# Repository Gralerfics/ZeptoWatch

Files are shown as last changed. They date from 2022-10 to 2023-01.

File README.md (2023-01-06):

# ZeptoWatch

A smart watch based on STM32F405RGT6.

基于 STM32F405RGT6 的智能手表 / 大号手环，特点是可以执行用户编写的 Python 脚本（应用程序），并提供板上资源的 Python 库封装。
使能为 USB FS Device，设备可像 U 盘一样被识别，并且内有 FAT 文件系统，脚本直接拖入根目录即可。设备端可在应用列表以左滑手势刷新列表，固件会进行扫描。

**【Improving.】**

---

**/Documents**.

  - imgs: Shots. 一些展示图。
  - docs: Documents. 一些粗糙的 API 说明和脚本程序示例。

**/Firmware**: The firmware for ZeptoWatch.

  - UI based on LVGL. LVGL 实现的图形交互界面。
  - Drivers for peripherals on board. 驱动封装。
  - Type-C Support. Type-C 接口支持。
  - USB Mass Storage Class. 可识别为 USB 大容量存储设备。
  - FatFs on EEPROM. 在 EEPROM 上建立 FAT 文件系统。
  - Applying [PikaScript](https://github.com/pikasTech/pikascript) as a built-in interpreter. 采用 PikaScript 作为内置 Python 解释器。
  - ......

<div align="center">
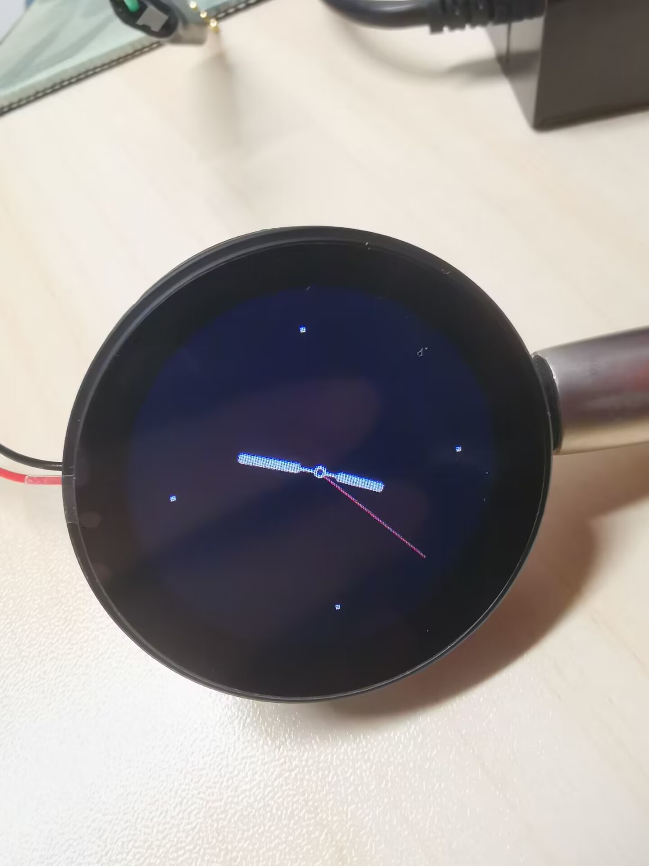
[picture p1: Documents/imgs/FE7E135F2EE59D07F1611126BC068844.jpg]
    
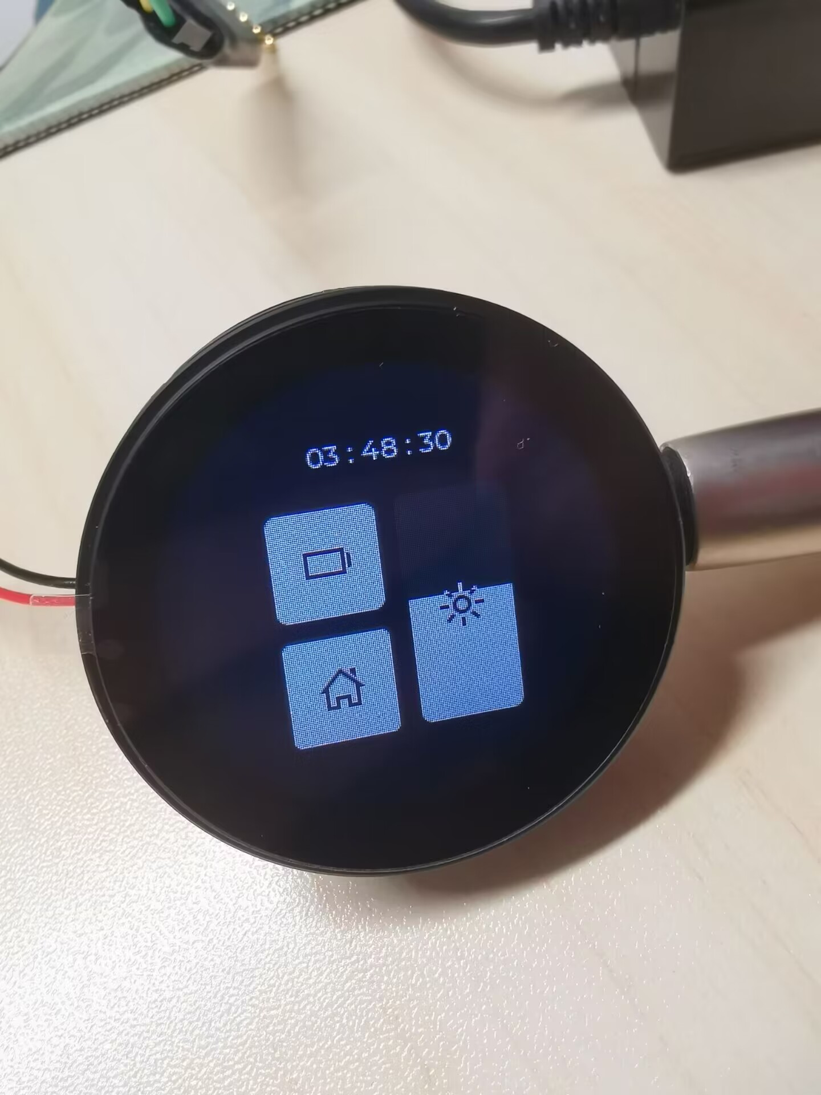
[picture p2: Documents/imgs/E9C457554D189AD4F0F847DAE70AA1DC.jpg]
    
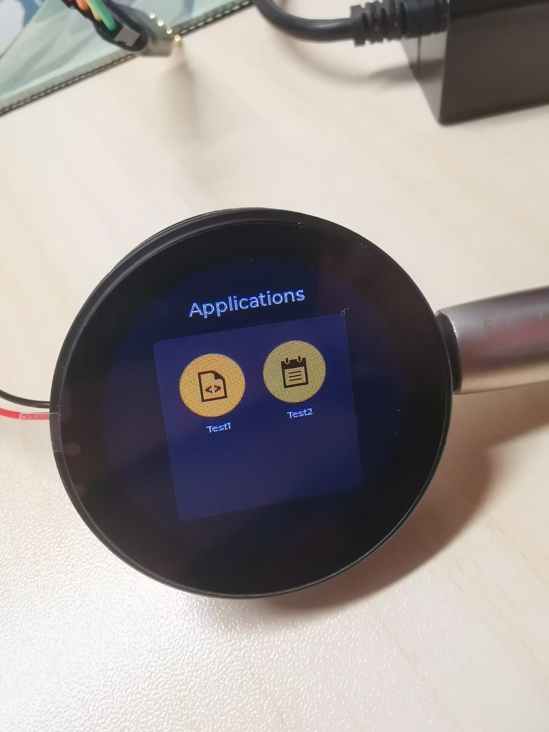
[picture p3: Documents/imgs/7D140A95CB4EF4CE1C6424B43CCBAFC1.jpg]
    
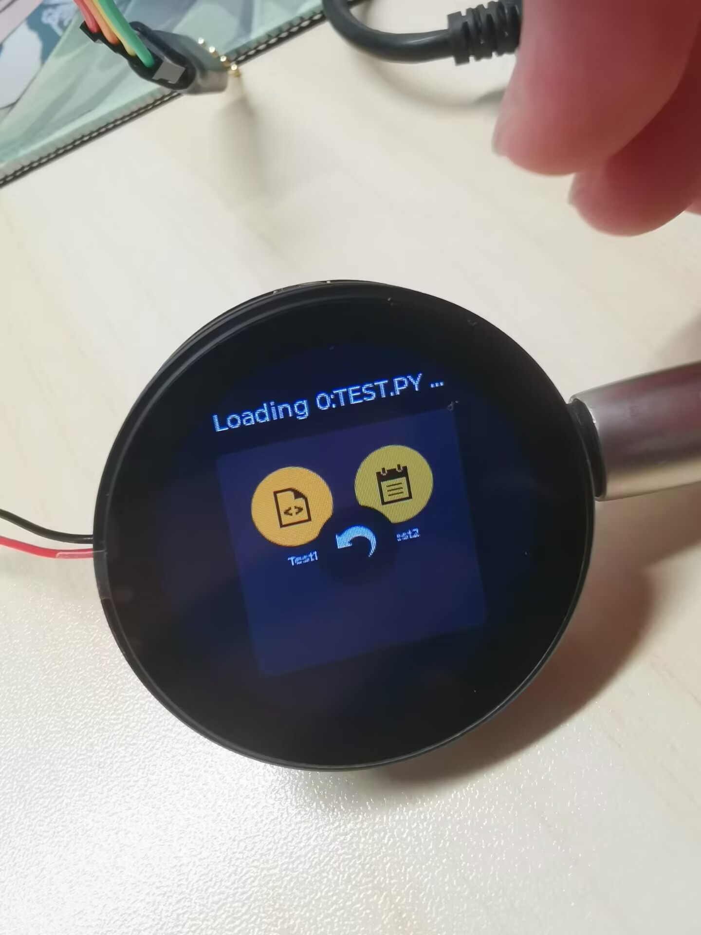
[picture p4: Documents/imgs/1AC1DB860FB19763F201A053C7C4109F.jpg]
    
</div>

**/Hardware**: PCBs & Schematics.

- Version 0.0: Test. 原型验证。

- Version 1.0: Polish up the schematics. Be not implemented. 初稿，存在问题。

- Version 2.0: There are some **mistakes** that would be modified in Ver.3.0. 第二版多处采取了一些更主流的方案，尚有一些小问题。

- Version 3.0: **Stacked design**. 第三版采用两块叠板设计。

<div align="center">
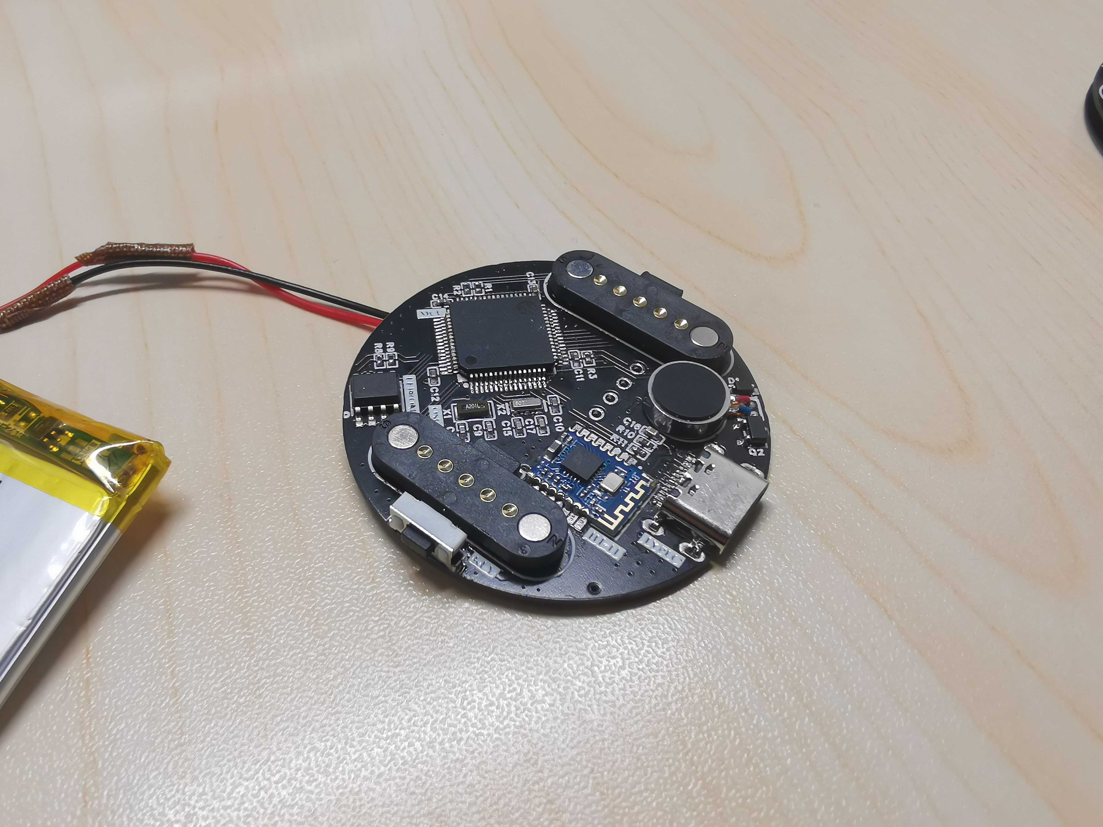
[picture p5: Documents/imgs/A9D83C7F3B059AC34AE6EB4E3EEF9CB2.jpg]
    
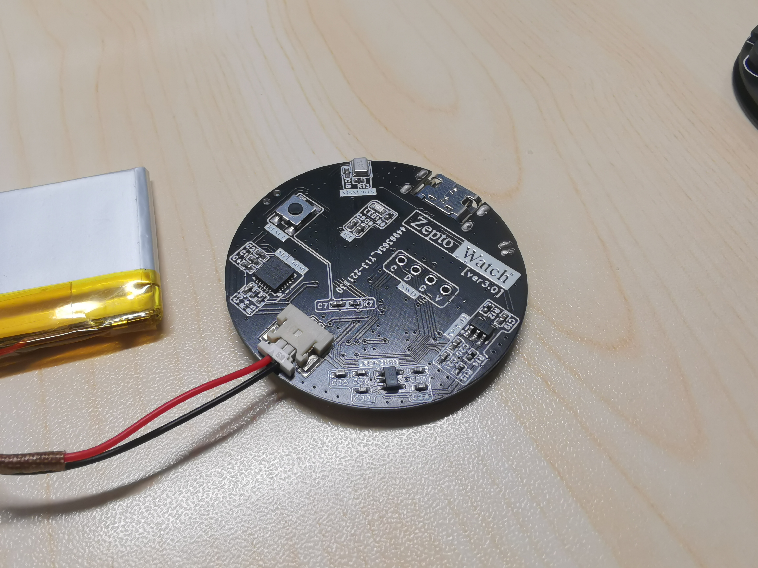
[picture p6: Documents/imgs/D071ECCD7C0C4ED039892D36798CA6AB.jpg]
    
</div>

<div align="center">
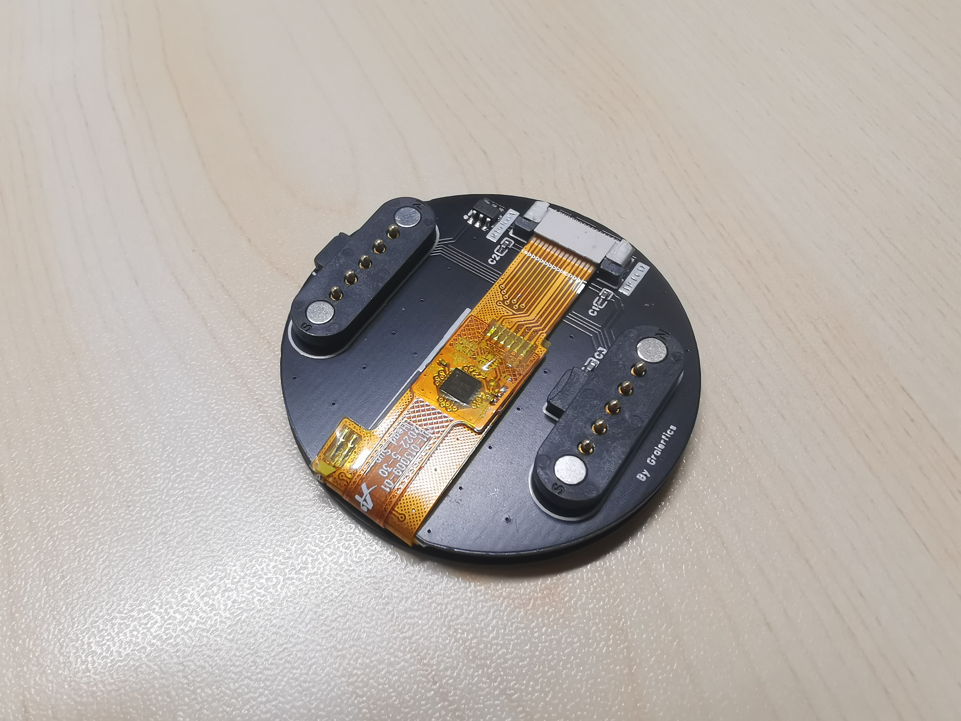
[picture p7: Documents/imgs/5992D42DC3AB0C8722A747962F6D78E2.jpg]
    
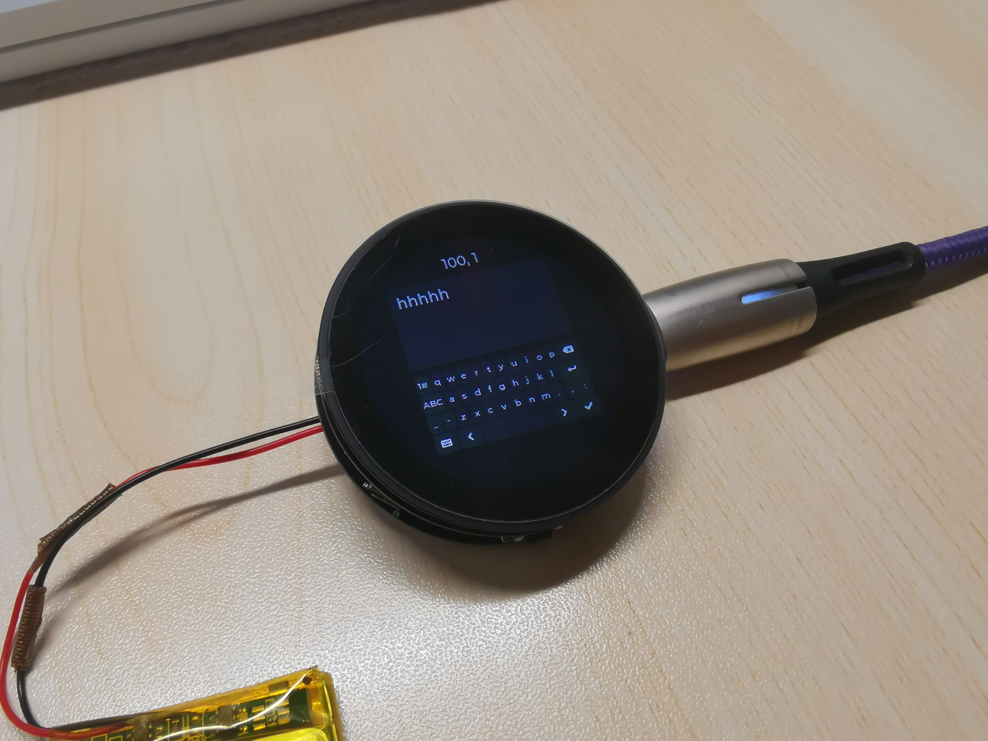
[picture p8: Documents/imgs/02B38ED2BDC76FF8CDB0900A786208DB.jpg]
    
</div>

- Version 4.0: Expectations. To be designed. 预期改进设计，详见第三版原理图注释。

**/Software/Scripts**: Some example scripts. 一些示例应用程序。

- BATUTIL.PY: 电源插拔检测和电池电压采样测试，字体大小变更测试。

- CALCAPP.PY: 简单的**计算器**，按钮阵列测试。

- FREQ.PY: 乱跳的**频谱显示**，麦克风、lvgl 样式、FFT (arm_math) 测试。

- LVTEST.PY: lvgl 测试，单个按钮与点击事件回调。

- MERITS.PY: **电 子 木 鱼**，内置图片资源获取、振动马达测试。

- SETTINGS.PY: 时间设置，roller 和 rtc 接口测试，设置界面已弃用改为内置。

- TEST.PY: 屏幕亮度变更、温度传感器测试。

- BALANCE.PY: 简单的**刚体模拟**小程序，用 IMU 加速度计给控件施加向下的模拟重力，顺便加了个边界反弹。

- GRAVITY.PY: BALANCE 的一个物体变为五个。

**/Structure**: Models in SolidWorks **(Just drafts, do not match the current PCB design)**. 无关的外壳设计，和实际设计的 PCB 不匹配，留档用。

---

An example script:
```python
###ICON=scripts;NAME=LightTest;COLOR=16751415###

import ZeptoWatchStdLib as zws
import ZeptoWatchPeriphLib as zwp

zwp.IMU.initialize()

i = 5
j = 1
while 1 == 1:
    zws.Display.setBrightness(i)
    if i >= 95:
        j = -1
    if i <= 5:
        j = 1
    i = i + j

    k = zwp.IMU.getTemperature()
    print(k)

    zws.System.delayMs(3)

###END###
```

The first line contains the basic information of the customized applications. Icons can be now only chosen from the built-in icons. By the way, the current implementation of the parsing method is just for testing and is very silly, so please follow the format strictly.
```python
###ICON=scripts;NAME=LightTest;COLOR=16751415###
```

The last line exists as another silly way to solve the problem of illegal characters at the end of the file when it is read by FatFs (I have temporarily no idea about where are they from. Maybe it has something to do with the fact that I edited the file by accessing the USB under Windows.).
```python
###END###
```

The output has been [retargeted](https://zhuanlan.zhihu.com/p/145801160) to USART6.
```python
print(k)
```

Drivers for resources on board are provided in the customized packages, including IMU, LCD, Microphone, etc.
```python
import ZeptoWatchStdLib as zws
import ZeptoWatchPeriphLib as zwp
```

If you want the rest of the system to be accessible at the same time, use ```ZeptoWatchStdLib.System.delayMs(time: int)``` in the script loop, which is implemented by FreeRTOS's ```osStatus osDelay (uint32_t millisec);```, in order to ensure that functions such as drop-down menus and clock ticking can remain active while the script is running.
```python
zws.System.delayMs(3)
```

A requirement from PikaScript is that all the spacing should be 4x spaces.
```python
while 1 == 1:
    zws.Display.setBrightness(i)
    if i >= 95:
        j = -1
    if i <= 5:
        j = 1
    i = i + j
```

---

Thanks for reading.

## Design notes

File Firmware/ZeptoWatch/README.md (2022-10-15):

# ZeptoWatch
Smart watch based on STM32F405RGT6.

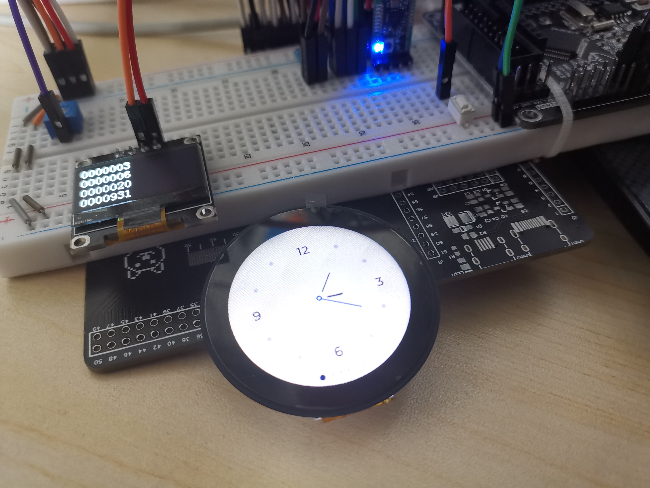
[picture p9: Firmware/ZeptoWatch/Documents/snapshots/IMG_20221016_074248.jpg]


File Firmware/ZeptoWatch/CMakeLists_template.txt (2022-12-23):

set(CMAKE_SYSTEM_NAME Generic)
set(CMAKE_SYSTEM_VERSION 1)
cmake_minimum_required(VERSION 3.23)

# specify cross-compilers and tools
set(CMAKE_C_COMPILER arm-none-eabi-gcc)
set(CMAKE_CXX_COMPILER arm-none-eabi-g++)
set(CMAKE_ASM_COMPILER  arm-none-eabi-gcc)
set(CMAKE_AR arm-none-eabi-ar)
set(CMAKE_OBJCOPY arm-none-eabi-objcopy)
set(CMAKE_OBJDUMP arm-none-eabi-objdump)
set(SIZE arm-none-eabi-size)
set(CMAKE_TRY_COMPILE_TARGET_TYPE STATIC_LIBRARY)

# project settings
project(ZeptoWatch C CXX ASM)
set(CMAKE_CXX_STANDARD 17)
set(CMAKE_C_STANDARD 11)

# PikaScript - [USER]
add_compile_definitions(PIKA_CONFIG_ENABLE)

#Uncomment for hardware floating point
add_compile_definitions(ARM_MATH_CM4;ARM_MATH_MATRIX_CHECK;ARM_MATH_ROUNDING)
add_compile_options(-mfloat-abi=hard -mfpu=fpv4-sp-d16)
add_link_options(-mfloat-abi=hard -mfpu=fpv4-sp-d16)

#Uncomment for software floating point
#add_compile_options(-mfloat-abi=soft)

add_compile_options(-mcpu=cortex-m4 -mthumb -mthumb-interwork)
add_compile_options(-ffunction-sections -fdata-sections -fno-common -fmessage-length=0)

# uncomment to mitigate c++17 absolute addresses warnings
#set(CMAKE_CXX_FLAGS "${CMAKE_CXX_FLAGS} -Wno-register")

# Enable assembler files preprocessing
add_compile_options($<$<COMPILE_LANGUAGE:ASM>:-x$<SEMICOLON>assembler-with-cpp>)

if ("${CMAKE_BUILD_TYPE}" STREQUAL "Release")
    message(STATUS "Maximum optimization for speed")
    add_compile_options(-Ofast)
elseif ("${CMAKE_BUILD_TYPE}" STREQUAL "RelWithDebInfo")
    message(STATUS "Maximum optimization for speed, debug info included")
    add_compile_options(-Ofast -g)
elseif ("${CMAKE_BUILD_TYPE}" STREQUAL "MinSizeRel")
    message(STATUS "Maximum optimization for size")
    add_compile_options(-Os)
else ()
    message(STATUS "Minimal optimization, debug info included")
    #    add_compile_options(-Og -g)
    add_compile_options(-O0)
endif ()

include_directories(
        /
        Core/Inc
        Drivers/STM32F4xx_HAL_Driver/Inc
        Drivers/STM32F4xx_HAL_Driver/Inc/Legacy
        Drivers/CMSIS/Device/ST/STM32F4xx/Include
        Drivers/CMSIS/Include
        FATFS/App
        FATFS/Target
        Libraries
        Libraries/lvgl
        Libraries/lvgl/porting
        Libraries/lvgl/src/core
        Libraries/PikaScript/pikascript-api
        Libraries/PikaScript/pikascript-core
        Middlewares/ST/ARM/DSP/Inc
        Middlewares/ST/STM32_USB_Device_Library/Class/MSC/Inc
        Middlewares/ST/STM32_USB_Device_Library/Core/Inc
        Middlewares/Third_Party/FatFs/src/
        Middlewares/Third_Party/FreeRTOS/Source/CMSIS_RTOS
        Middlewares/Third_Party/FreeRTOS/Source/include
        Middlewares/Third_Party/FreeRTOS/Source/portable/GCC/ARM_CM4F
        USB_DEVICE/App
        USB_DEVICE/Target
        ZeptoWatch
        ZeptoWatch/BuiltIns
        ZeptoWatch/BuiltIns/UI
        ZeptoWatch/Drivers/battery
        ZeptoWatch/Drivers/bt
        ZeptoWatch/Drivers/eeprom
        ZeptoWatch/Drivers/imu
        ZeptoWatch/Drivers/lcd
        ZeptoWatch/Drivers/microphone
        ZeptoWatch/Drivers/rtc
        ZeptoWatch/Drivers/system
        ZeptoWatch/Drivers/vibrator
        ZeptoWatch/Ports
        ZeptoWatch/Tasks
        ZeptoWatch/UI
        ZeptoWatch/Utils
)

add_definitions(-DUSE_HAL_DRIVER -DSTM32F405xx)

file(GLOB_RECURSE SOURCES
        "Core/*.*"
        "Drivers/*.*"
        "FATFS/*.*"
        "Libraries/lvgl/*.*"
        "Libraries/PikaScript/*.c"
        "Libraries/PikaScript/*.h"
        "Middlewares/*.*"
        "startup/*.*"
        "USB_DEVICE/*.*"
        "ZeptoWatch/*.*"
)

set(LINKER_SCRIPT ${CMAKE_SOURCE_DIR}/STM32F405RGTx_FLASH.ld)

add_link_options(-Wl,-gc-sections,--print-memory-usage,-Map=${PROJECT_BINARY_DIR}/${PROJECT_NAME}.map)
add_link_options(-mcpu=cortex-m4 -mthumb -mthumb-interwork)
add_link_options(-T ${LINKER_SCRIPT})

add_executable(${PROJECT_NAME}.elf ${SOURCES} ${LINKER_SCRIPT})

# Arm-math - [USER]
add_library(arm_math STATIC IMPORTED)
set_target_properties(arm_math PROPERTIES IMPORTED_LOCATION ${CMAKE_SOURCE_DIR}/Middlewares/ST/ARM/DSP/Lib/libarm_cortexM4lf_math.a)
target_link_libraries(${PROJECT_NAME}.elf arm_math)

set(HEX_FILE ${PROJECT_BINARY_DIR}/${PROJECT_NAME}.hex)
set(BIN_FILE ${PROJECT_BINARY_DIR}/${PROJECT_NAME}.bin)

add_custom_command(TARGET ${PROJECT_NAME}.elf POST_BUILD
        COMMAND ${CMAKE_OBJCOPY} -Oihex $<TARGET_FILE:${PROJECT_NAME}.elf> ${HEX_FILE}
        COMMAND ${CMAKE_OBJCOPY} -Obinary $<TARGET_FILE:${PROJECT_NAME}.elf> ${BIN_FILE}
        COMMENT "Building ${HEX_FILE}
Building ${BIN_FILE}")

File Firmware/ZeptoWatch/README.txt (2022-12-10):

1、为了可以格式化小容量空间，FATFS的原文件需要修改，而CubeMX重新生成会覆盖，故需手动修改ff.c。
修改参考：https://blog.csdn.net/qq_40824852/article/details/123357022，第六部分：大致就是某处“sz_vol -= b_vol;”注释掉；某处“if (sz_vol < 128) return FR_MKFS_ABORTED;”注释掉。
当然，也只有未格式化时需要f_mkfs，如果已经格式化了之后不损坏就不需要管了，这里作个记录。

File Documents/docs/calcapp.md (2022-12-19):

# Comments for Calculator Example

---

```python
###ICON=calc;NAME=Calculator;COLOR=13726207;###

import pika_lvgl as lv
import ZeptoWatchStdLib as zws

instr = ''
sym = ''
a = 0
b = 0

lb = lv.label(zws.Display.getField())
lb.set_align(lv.ALIGN.CENTER)
lb.set_width(140)
lb.set_y(-80)
lb.set_text(instr)

btnCode = ['7', '8', '9', '+', '4', '5', '6', '-', '1', '2', '3', '*', '.', '0', '=', '/']
btnList = []
lbList = []

def event_cb_btns(e):
    code = e.get_code()
    if code == lv.EVENT.CLICKED:
        global instr, sym, a, b
        idx = int(e.get_target().get_id())
        if btnCode[idx] == '=':
            if instr == '':
                b = 0
            else:
                b = float(instr)
            res = ''
            if sym == '+':
                res = str(a + b)
            elif sym == '-':
                res = str(a - b)
            elif sym == '*':
                res = str(a * b)
            elif sym == '/':
                if b == 0:
                    res = 'Math Error!'
                else:
                    res = str(a / b)
            else:
                res = str(b)
            lb.set_text(res)
            a = float(res)
            sym = '='
            instr = ''
        elif btnCode[idx] == '+' or btnCode[idx] == '-' or btnCode[idx] == '*' or btnCode[idx] == '/':
            if sym == '':
                if instr == '':
                    a = 0
                else:
                    a = float(instr)
            sym = btnCode[idx]
            instr = ''
            lb.set_text(sym)
        else:
            if sym == '=':
                sym = ''
            instr += btnCode[idx]
            lb.set_text(instr)

for i in range(16):
    btnList.append(lv.btn(zws.Display.getField()))
    btnList[i].set_id(str(i))
    btnList[i].set_align(lv.ALIGN.CENTER)
    btnList[i].set_size(32, 32)
    btnList[i].set_x((i % 4) * 40 - 60)
    btnList[i].set_y(int(i / 4) * 40 - 45)
    btnList[i].add_event_cb(event_cb_btns, lv.EVENT.CLICKED, 0)

    lbList.append(lv.label(zws.Display.getField()))
    lbList[i].set_align(lv.ALIGN.CENTER)
    lbList[i].set_x((i % 4) * 40 - 60)
    lbList[i].set_y(int(i / 4) * 40 - 45)
    lbList[i].set_text(btnCode[i])

while 1 == 1:
    zws.System.delayMs(5)

###END###
```

1. 首先程序开头和结尾的的注释：

```python
###ICON=calc;NAME=Calculator;COLOR=13726207;###
...
###END###
```

- 首先开头的注释包含应用信息。

  - **参数**：
  `ICON`指定图标，目前可选`scripts (默认)`、`timer`、`calc`、`canlendar`、`settings`、`info`、`clock`、`check`、`notes`；
  `NAME`指定应用名称，默认为文件路径；
  `COLOR`指定应用图标颜色，十进制，转换为十六进制后有六位，每两位分别代表`RGB (0 - 255)`值。 
  例如：上例中`13726207`为十六进制`0xD171FF`，`D1`为`209`代表红色值，依此类推。用 Windows 自带计算器的程序员模式看就行。

  - **要求**：
开头三个井号是必须的，结束至少一个井号，写三个对称好看点；
内部每个参数用分号隔开，顺序可以变动，最后一个参数结束也要加分号；
参数名和参数值用一个等号连接；
参数名要大写；参数值长度不超过`30`；
非法参数名会被忽略，但长度不要超过`8`；
未成功赋值的参数将使用默认值`ICON=scripts;NAME=[文件名];COLOR=16751415`。
当然，因为解析部分的逻辑很简单粗暴，按照示例的格式来是最稳的。

- 结尾的注释最好加上，先前读取程序时末尾有非法字符，暂时的解决方案就是检测`#END#`然后把后面的内容都忽略掉。

2. 接下来是导入所需的包：
```python
import pika_lvgl as lv
import ZeptoWatchStdLib as zws
```

这里用到了 UI 组件所以导入`pika_lvgl`包，便于使用起别名为`lv`；同样地，因为用到了`delayMs()`和`getField()`等，也要导入`ZeptoWatchStdLib`包，起别名为`zws`。

虽然其实初始化时几个包都导入了，不过为了完整性还是规范些写。

3. 下面先说主循环：
```python
while 1 == 1:
    zws.System.delayMs(5)
```

主循环中如果不想阻塞系统其它任务请调用`zws.System.delayMs()`。该函数背后是`FreeRTOS`的`osDelay`，在延时中会由`RTOS`调度执行系统其他任务，比如绘制 UI、亮度和电量同步等。

缺点就是最小时间单位长达一毫秒——但如果不调用就会阻塞，UI 不会更新，系统也会卡死，因为触摸检测之类都被阻塞了，进了死循环。当然，`ZeptoWatchStdLib`也提供了一个`.Display.lvglUpdate()`方法，用于手动触发`lvgl`任务处理，可以使 UI 更新和触摸继续工作，但亮度和电量检测之类还是罢工，晚些都把手动的接口添加上，再加个配套的微秒级阻塞延时。

4. 然后以创建一个 Label 为例看下 UI 组件的配置：
```python
lb = lv.label(zws.Display.getField())
lb.set_align(lv.ALIGN.CENTER)
lb.set_width(140)
lb.set_y(-80)
```

这里是用构造方法`lv.label()`创建了一个`label`对象，参数是其父对象。UI 界面是一个树形结构，组件可以一级套一级，所以要传入它的父对象。

这里使用`zws.Display.getField()`获取应用界面的根对象(源代码中看就是`ui_Appfield`)。`lvgl`还提供了一个`lv.scr_act()`方法用于获取当前活动中的屏幕，不使用而专门封装一个`getField()`是为了防止例如应用界面加载时拉下下拉菜单导致组件画到下拉菜单上这种情况出现，所以尽量使用`getField()`。

然后创建后把对象保存到`lb`变量，之后对其进行操作即可。下面使用的都是`lv_obj`的成员方法，具体可以见`api.md`和`pika_lvgl.pyi`。

`lb.set_align`设置对齐方式，设为`lv.ALIGN.CENTER`的直观表现就是坐标系的原点`(0, 0)`之后就被定位在了屏幕正中。

设置居中对齐后，`lb.set_y(-80)`就把标签移动到比中心高`80px`的地方。横坐标默认为`0`。注：屏幕大小为`240x240px`。

`lb.set_width`设置宽度为`140px`，不设置也行，标签对象的默认宽度是适应内容宽度。

设置完后可以用`label`的成员方法设置标签的内容，例如`lb.set_text(str)`，`str`为字符串。

5. 可以看到`PikaScript`目前也支持`list`数据结构：
```python
btnCode = ['7', '8', '9', '+', '4', '5', '6', '-', '1', '2', '3', '*', '.', '0', '=', '/']
btnList = []
lbList = []
...
for i in range(16):
    btnList.append(lv.btn(zws.Display.getField()))
    btnList[i].set_id(str(i))
    btnList[i].set_align(lv.ALIGN.CENTER)
    btnList[i].set_size(32, 32)
    btnList[i].set_x((i % 4) * 40 - 60)
    btnList[i].set_y(int(i / 4) * 40 - 45)
    btnList[i].add_event_cb(event_cb_btns, lv.EVENT.CLICKED, 0)

    lbList.append(lv.label(zws.Display.getField()))
    lbList[i].set_align(lv.ALIGN.CENTER)
    lbList[i].set_x((i % 4) * 40 - 60)
    lbList[i].set_y(int(i / 4) * 40 - 45)
    lbList[i].set_text(btnCode[i])
```

前面的标签是计算器的输入和输出显示标签，被放在屏幕上端。这里则是`16`个按键阵列的生成。

首先定义好几个`list`，一个存放各个按键的标签字符串，一个存放十六个`btn`，一个存放十六个`label`对象。

下面`for`循环（可以看到`range`也支持），按钮和标签分别创建后添加至列表，然后进行设置，具体的和前面一样就不说了，看函数名字就能猜。

特别的是`btn`还用了一个`.add_event_cb`方法，用于绑定事件，见下。

6. 关于事件绑定：
```python
def event_cb_btns(e):
    code = e.get_code()
    if code == lv.EVENT.CLICKED:
        idx = int(e.get_target().get_id())
        ...

for i in range(16):
    btnList[i].set_id(str(i))
    ...
    btnList[i].add_event_cb(event_cb_btns, lv.EVENT.CLICKED, 0)

```

按钮点击之后需要处理，这时候就需要给按钮绑定点击事件。`add_event_cb`三个参数，第一个是回调函数的名字，第二个是事件类型，第三个是`user_data`。

回调函数前边定义了放进来就行。

事件类型参见文档`EVENT`，常用的就点击，也就是`lv.EVENT.CLICKED`。

`user_data`可以给回调函数传递数据，比如像上面十六个按钮共用一个回调函数，可以用这个参数来区分到底是哪个按钮被点击了。但是获取这个数据的接口他好像没封装，所以这种方法先不能用，就传个`0`进去空着。
替代的方法也就是上面用到的，给每个`btn`对象`set_id`设置一个`id`，在回调函数中查看点击对象的`id`来区分。

回调函数接受一个参数，假设叫`e`。这个`e`目前由两个方法，一个是`.get_code()`，可以获取触发的事件类型，每次要先判断一下是不是你要的事件，具体见上；另一个是`.get_target()`，返回触发事件的对象，比如你按了第七个按钮，就可以获取第七个按钮的对象引用，所以可以通过这个方法来获取按钮的`id`，区分是哪个按钮被点击了，具体见上。

上面实例中回调函数大半部分是混乱但能跑的计算器逻辑，涉及到按钮点击的部分就是上面截取出的部分。

7. 一些备注：

这是关于`Python`语法的，函数中获取全局变量记得`global`。

`Python`的`for`、`if`结构和其他的不太一样，注意一下。还有逻辑运算不是`&&`之类，而是`and`之类。

所有缩进都是四个空格为基础，而不是等缩进就行，这是`PikaScript`的要求。

---

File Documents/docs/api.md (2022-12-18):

# APIs for ZeptoWatch Scripts

---

0. `PikaScript` (Subset of Python3)

- 

1. `PikaStdLib` (Package, Recommend: `import PikaStdLib as std`)

- 

2. `ZeptoWatchStdLib` (Package, Recommend: `import ZeptoWatchStdLib as zws`)

```python
class System:
    def delayMs(self, time: int): ...
    # 用 FreeRTOS 的 osDelay 实现, 调用它以允许其它任务并行

class Display:
    def getField(self) -> lv_obj: ...
    # 获取应用界面屏幕的对象, 创建 lvgl 对象时作为根对象, 退出应用时会被清空.
    # 不建议使用 pika_lvgl.scr_act(), 如果在应用界面进入下拉栏时调用会导致组件显示到下拉栏.
    # 总之就是创建最初一级 UI 对象时用到, 例如: lb = lv.label(zws.Display.getField()).
    # 上例中利用 lv.label() 创建 label 对象, 使用 getField 获取应用页面作为其父对象.
    
    def setBrightness(self, val: int): ... 
    # 设置屏幕亮度, 值为 [0, 100].
    # 已经经过映射, 也就是 0 不代表彻底熄灭, 且亮暗变化更连续些.
    
    def getBrightness(self) -> int: ...
    # 获取当前屏幕亮度, 按键熄屏导致的亮度变化不算.

class Clock:
    def getHours(self) -> int: ...
    def getMinutes(self) -> int: ...
    def getSeconds(self) -> int: ...
    def getYear(self) -> int: ...
    def getMonth(self) -> int: ...
    def getDay(self) -> int: ...
    def getWeekDay(self) -> int: ...
    # 以上分别为获取实时时钟的时、分、秒、年、月、日、星期.
```

3. `ZeptoWatchPeriphLib` (Package, Recommend: `import ZeptoWatchPeriphLib as zwp`)

```python
class IMU:
    def initialize(self): ...
    # 初始化 IMU, 使用 IMU 前调用. 不过系统开机时自动初始化了, 可以不管.
    
    def getTemperature(self) -> int: ...
    # 获取温度原始值, 好像为温度值乘 100 后的结果.
    
    def getGyroscope(self) -> list: ...
    # 获取三轴角加速度, 返回一个三元素列表.
    # [-32768, 32767] 对应 [-2000dps, 2000dps], dps: degree per second.
    
    def getAccelerometer(self) -> list: ...
    # 获取三轴加速度, 返回一个三元素列表.
    # [-32768, 32767] 对应 [-2g, 2g].

class Battery:
    def isCharging(self) -> int: ...
    # 获取 Type-C 口是否接上电源.
    
    def getRawData(self) -> int: ...
    # 获取电池 ADC 采样原始值, 不准得很, 忽略吧.

class Microphone:
    def startSampling(self): ...
    # 开启麦克风采样, 使用前要调用.
    
    def stopSampling(self): ...
    # 停止麦克风采样.

    def getRawData(self) -> int: ...
    # 获取麦克风当前采样值.

class Vibrator:
    def vibrate(self, ms: int, pulse: int): ...
    # 振动马达振动, 持续 ms 毫秒, 占空比 pulse. 虽然效果不太舒适的样子.
    # 这玩意快能当蜂鸣器了 ...

    def stop(self): ...
    # 强制停止振动.
```

4. `pika_lvgl` (Package, Recommend: `import pika_lvgl as lv`)

东西很多, 可以去下个 Squareline Studio 鼠标点点看, 都是和 API 对应的. 当然, 简单能用的界面就用 label 和 btn 也足够了.

- `lv_obj`, 所有 lvgl 对象的父类, 挑一些注释一下.

```python
class lv_obj:
    def __init__(self, parent: lv_obj): ...
    
    def add_state(self, state: int): ...
    # 添加 state, 可取值见后 STATE.
    
    def add_flag(self, flag: int): ...
    def clear_flag(self, flag: int): ...
    # 添加或清除 flag, 例如隐藏等, 具体见后 flag_t
    
    def add_event_cb(self, event_cb: any, filter: int, user_data: pointer): ...
    # 添加回调函数. 例如: btn.add_event_cb(event_cb_btn, lv.EVENT.CLICKED, 0).
    # 上例为按钮添加了点击事件, btn 若被点击就会执行 event_cb_btn(e) 函数, 并传入一个 lv_event 参数.
    # lv_event 和 EVENT 可取值见后.
    
    def add_style(self, style: style_t, selector: int): ...
    # 添加样式, 见后 style_t.
    
    def set_pos(self, x: int, y: int): ...
    def set_x(self, x: int): ...
    def set_y(self, y: int): ...
    def set_size(self, w: int, h: int): ...
    def refr_size(self) -> int: ...
    def set_width(self, w: int): ...
    def set_height(self, h: int): ...
    def set_content_width(self, w: int): ...
    def set_content_height(self, h: int): ...
    # 各种设置大小、位置的 API.
    
    def set_layout(self, layout: int): ...
    def is_layout_positioned(self) -> int: ...
    def mark_layout_as_dirty(self): ...
    def update_layout(self): ...
    # 关于 Layout 的.
    
    def set_align(self, align: int): ...
    def align(self, align: int, x_ofs: int, y_ofs: int): ...
    def align_to(self, base: lv_obj, align: int, x_ofs: int, y_ofs: int): ...
    def center(self): ...
    # 关于对齐的, ALIGN 也见后. 前面设置坐标的基准是 ALIGN.
    # 例如: 如果设置为 lv.ALIGN.CENTER, 则正中间为坐标原点 (0,0).
    
    def get_x(self) -> int: ...
    def get_x2(self) -> int: ...
    def get_y(self) -> int: ...
    def get_y2(self) -> int: ...
    def get_x_aligned(self) -> int: ...
    def get_y_aligned(self) -> int: ...
    def get_width(self) -> int: ...
    def get_height(self) -> int: ...
    def get_content_width(self) -> int: ...
    def get_content_height(self) -> int: ...
    def get_self_width(self) -> int: ...
    def get_self_height(self) -> int: ...
    # 尺寸和位置参数的获取
    
    def refresh_self_size(self) -> int: ...
    def refr_pos(self): ...
    def move_to(self, x: int, y: int): ...
    def move_children_by(self, x_diff: int, y_diff: int, ignore_floating: int): ..
    def transform_point(self, p: point_t, recursive: int, inv: int): ...
    def invalidate(self): ...
    # 没用过不知道
    
    def is_visible(self) -> int: ...
    # 是否可见
    
    def set_ext_click_area(self, size: int): ...
    def hit_test(self, point: point_t) -> int: ...
    # 关于点击
    
    def set_flex_flow(self, flow: int): ...
    def set_flex_grow(self, value: int): ...
    def set_flex_align(self, main_place: int, cross_place: int, align: int): ...
    # 关于 Flex
    
    def set_id(self, id: str): ...
    def get_id(self) -> str: ...
    # 关于 id 的设置. 这个可以用来给同类组件打标签, 方便事件回调识别.
    # 例如计算器的例程中 16 个按钮分别 set_id 了各自的 id,
    # 这样在回调中就可以利用 e.get_target().get_id() 来识别是哪个按钮被点击了.
    
    def clean(self): ...
    # 清理子组件
```

- `label`, 标签, 首先继承 lv_obj, 也就是以上 lv_obj 里的方法都有, 其次还有以下成员:

```python
class label(lv_obj):
    def __init__(self, parent: lv_obj): ...
    
    def set_text(self, txt: str): ...
    # 设置标签的文字内容, 最常用.
    
    def set_long_mode(self, mode: int): ...
    def set_recolor(self, en: int): ...
    def set_style_text_align(self, value: int, selector: int): ...
```

- `btn`, 按钮, 啥也没封装, 全靠 lv_obj 的成员.

```python
class btn(lv_obj):
    def __init__(self, parent: lv_obj): ...
```

- 其它诸如 `bar`, `checkbox`, `dropdown`, `roller`, `slider`, `switch`, `table`, `img`, `textarea`, `arc` 等控件, 不包含 lvgl 所有控件, 例如 `panel` 和 `chart` 好像就没有, 但基本都全了. **具体可见** `Firmware/Libraries/PikaScript/pika_lvgl.pyi`, 包括其它库的定义也在该目录.

**下面是一些参数数据类型的定义:**

- `STATE`, state 的取值. 例如可以设置按钮的显示状态是普通还是按下之类.

```python
class STATE:
    DEFAULT: int
    CHECKED: int
    FOCUSED: int
    FOCUS_KEY: int
    EDITED: int
    HOVERED: int
    PRESSED: int
    SCROLLED: int
    DISABLED: int
    USER_1: int
    USER_2: int
    USER_3: int
    USER_4: int
    ANY: int
    def __init__(self): ...
```

- `flag_t`, flag 的取值. 例如 add_flag 添加下面第一个 HIDDEN 可以隐藏对象.

```python
class flag_t:
    HIDDEN: int
    CLICKABLE: int
    CLICK_FOCUSABLE: int
    CHECKABLE: int
    SCROLLABLE: int
    SCROLL_ELASTIC: int
    SCROLL_MOMENTUM: int
    SCROLL_ONE: int
    SCROLL_CHAIN_HOR: int
    SCROLL_CHAIN_VER: int
    SCROLL_CHAIN: int
    SCROLL_ON_FOCUS: int
    SCROLL_WITH_ARROW: int
    SNAPPABLE: int
    PRESS_LOCK: int
    EVENT_BUBBLE: int
    GESTURE_BUBBLE: int
    ADV_HITTEST: int
    IGNORE_LAYOUT: int
    FLOATING: int
    OVERFLOW_VISIBLE: int
    LAYOUT_1: int
    LAYOUT_2: int
    WIDGET_1: int
    WIDGET_2: int
    USER_1: int
    USER_2: int
    USER_3: int
    USER_4: int
    def __init__(self): ...
```

- `lv_event`, 回调函数可获取的信息.

```python
class lv_event:
    def get_code(self) -> int: ... # 获取事件类型
    def get_target(self) -> lv_obj: ... # 获取触发事件的对象
```

- `EVENT`, 可添加的事件类型. 需在回调函数中条件判断事件类型. 例如:
```python
def event_cb_btn(e):
    code = e.get_code() # 见 lv_event, 获取事件类型
    if code == lv.EVENT.CLICKED:
        pass
```

```python
class EVENT:
    ALL: int
    PRESSED: int
    PRESSING: int
    PRESS_LOST: int
    SHORT_CLICKED: int
    LONG_PRESSED: int
    LONG_PRESSED_REPEAT: int
    CLICKED: int
    RELEASED: int
    SCROLL_BEGIN: int
    SCROLL_END: int
    SCROLL: int
    GESTURE: int
    KEY: int
    FOCUSED: int
    DEFOCUSED: int
    LEAVE: int
    HIT_TEST: int
    COVER_CHECK: int
    REFR_EXT_DRAW_SIZE: int
    DRAW_MAIN_BEGIN: int
    DRAW_MAIN: int
    DRAW_MAIN_END: int
    DRAW_POST_BEGIN: int
    DRAW_POST: int
    DRAW_POST_END: int
    DRAW_PART_BEGIN: int
    DRAW_PART_END: int
    VALUE_CHANGED: int
    INSERT: int
    REFRESH: int
    READY: int
    CANCEL: int
    DELETE: int
    CHILD_CHANGED: int
    CHILD_CREATED: int
    CHILD_DELETED: int
    SCREEN_UNLOAD_START: int
    SCREEN_LOAD_START: int
    SCREEN_LOADED: int
    SCREEN_UNLOADED: int
    SIZE_CHANGED: int
    STYLE_CHANGED: int
    LAYOUT_CHANGED: int
    GET_SELF_SIZE: int
    PREPROCESS: int
    def __init__(self): ...
```

- `style_t`, style 相关. 建立 style_t 的实例后传入 add_style.

```python
class style_t:
    def __init__(self): ...
    def init(self): ...
    def set_width(self, value: int): ...
    def set_min_width(self, value: int): ...
    def set_max_width(self, value: int): ...
    def set_height(self, value: int): ...
    def set_min_height(self, value: int): ...
    def set_max_height(self, value: int): ...
    def set_x(self, value: int): ...
    def set_y(self, value: int): ...
    def set_align(self, value: int): ...
    def set_transform_width(self, value: int): ...
    def set_transform_height(self, value: int): ...
    def set_translate_x(self, value: int): ...
    def set_translate_y(self, value: int): ...
    def set_transform_zoom(self, value: int): ...
    def set_transform_angle(self, value: int): ...
    def set_transform_pivot_x(self, value: int): ...
    def set_transform_pivot_y(self, value: int): ...
    def set_pad_top(self, value: int): ...
    def set_pad_bottom(self, value: int): ...
    def set_pad_left(self, value: int): ...
    def set_pad_right(self, value: int): ...
    def set_pad_row(self, value: int): ...
    def set_pad_column(self, value: int): ...
    def set_bg_color(self, value: lv_color_t): ...
    def set_bg_opa(self, value: int): ...
    def set_bg_grad_color(self, value: lv_color_t): ...
    def set_bg_grad_dir(self, value: int): ...
    def set_bg_main_stop(self, value: int): ...
    def set_bg_grad_stop(self, value: int): ...
    def set_bg_dither_mode(self, value: int): ...
    def set_bg_img_src(self, value: bytes): ...
    def set_bg_img_opa(self, value: int): ...
    def set_bg_img_recolor(self, value: lv_color_t): ...
    def set_bg_img_recolor_opa(self, value: int): ...
    def set_bg_img_tiled(self, value: int): ...
    def set_border_color(self, value: lv_color_t): ...
    def set_border_opa(self, value: int): ...
    def set_border_width(self, value: int): ...
    def set_border_side(self, value: int): ...
    def set_border_post(self, value: int): ...
    def set_outline_width(self, value: int): ...
    def set_outline_color(self, value: lv_color_t): ...
    def set_outline_opa(self, value: int): ...
    def set_outline_pad(self, value: int): ...
    def set_shadow_width(self, value: int): ...
    def set_shadow_ofs_x(self, value: int): ...
    def set_shadow_ofs_y(self, value: int): ...
    def set_shadow_spread(self, value: int): ...
    def set_shadow_color(self, value: lv_color_t): ...
    def set_shadow_opa(self, value: int): ...
    def set_img_opa(self, value: int): ...
    def set_img_recolor(self, value: lv_color_t): ...
    def set_img_recolor_opa(self, value: int): ...
    def set_line_width(self, value: int): ...
    def set_line_dash_width(self, value: int): ...
    def set_line_dash_gap(self, value: int): ...
    def set_line_rounded(self, value: int): ...
    def set_line_color(self, value: lv_color_t): ...
    def set_line_opa(self, value: int): ...
    def set_arc_width(self, value: int): ...
    def set_arc_rounded(self, value: int): ...
    def set_arc_color(self, value: lv_color_t): ...
    def set_arc_opa(self, value: int): ...
    def set_arc_img_src(self, value: bytes): ...
    def set_text_color(self, value: lv_color_t): ...
    def set_text_opa(self, value: int): ...
    def set_text_letter_space(self, value: int): ...
    def set_text_line_space(self, value: int): ...
    def set_text_decor(self, value: int): ...
    def set_text_align(self, value: int): ...
    def set_radius(self, value: int): ...
    def set_clip_corner(self, value: int): ...
    def set_opa(self, value: int): ...
    def set_color_filter_opa(self, value: int): ...
    def set_anim_time(self, value: int): ...
    def set_anim_speed(self, value: int): ...
    def set_blend_mode(self, value: int): ...
    def set_layout(self, value: int): ...
    def set_base_dir(self, value: int): ...
    def reset(self): ...
    def register_prop(self, flag: int) -> int: ...
    def get_num_custom_props(self) -> int: ...
    def remove_prop(self, prop: int) -> int: ...
    def is_empty(self) -> int: ...
    def set_size(self, value: int): ...
    def set_pad_all(self, value: int): ...
    def set_pad_hor(self, value: int): ...
    def set_pad_ver(self, value: int): ...
    def set_pad_gap(self, value: int): ...
    def prop_has_flag(self, prop: int, flag: int) -> int: ...
    def set_flex_flow(self, value: int): ...
    def set_flex_main_place(self, value: int): ...
    def set_flex_cross_place(self, value: int): ...
    def set_flex_track_place(self, value: int): ...
    def set_flex_grow(self, value: int): ...
```

- `ALIGN`, align 的取值.

```python
class ALIGN:
    DEFAULT: int
    TOP_LEFT: int
    TOP_MID: int
    TOP_RIGHT: int
    BOTTOM_LEFT: int
    BOTTOM_MID: int
    BOTTOM_RIGHT: int
    LEFT_MID: int
    RIGHT_MID: int
    CENTER: int
    OUT_TOP_LEFT: int
    OUT_TOP_MID: int
    OUT_TOP_RIGHT: int
    OUT_BOTTOM_LEFT: int
    OUT_BOTTOM_MID: int
    OUT_BOTTOM_RIGHT: int
    OUT_LEFT_TOP: int
    OUT_LEFT_MID: int
    OUT_LEFT_BOTTOM: int
    OUT_RIGHT_TOP: int
    OUT_RIGHT_MID: int
    OUT_RIGHT_BOTTOM: int
    def __init__(self): ...
```

---

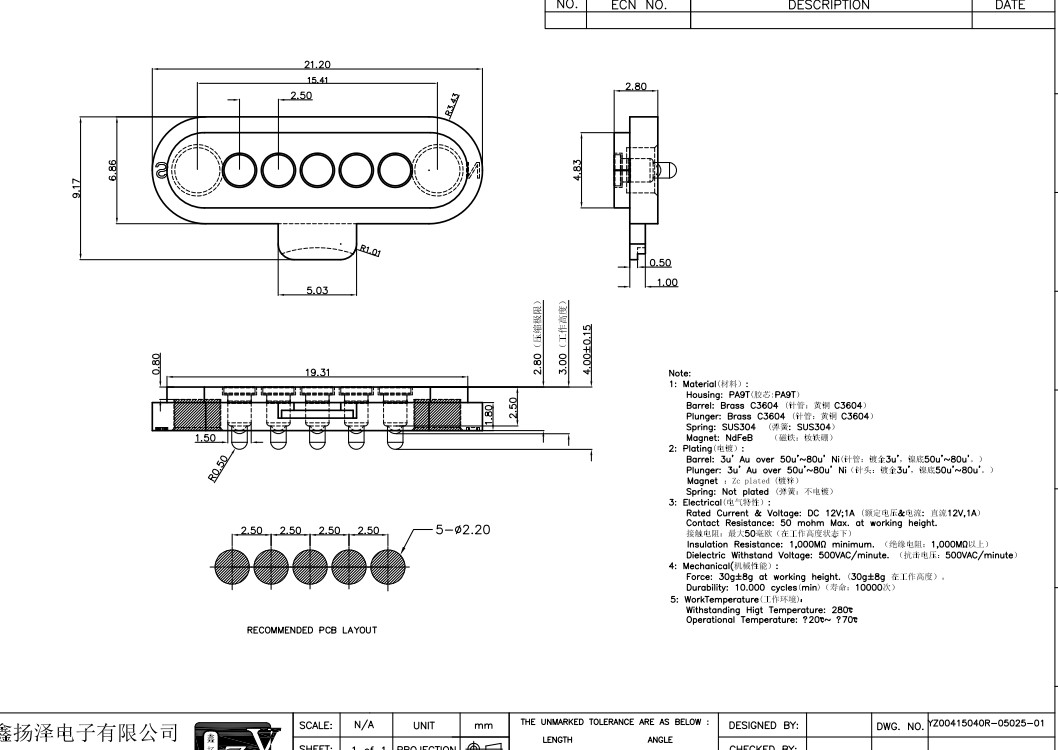
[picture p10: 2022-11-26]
Hardware/references/7266E34BBBE40DA085ACD75704D1471F.jpg

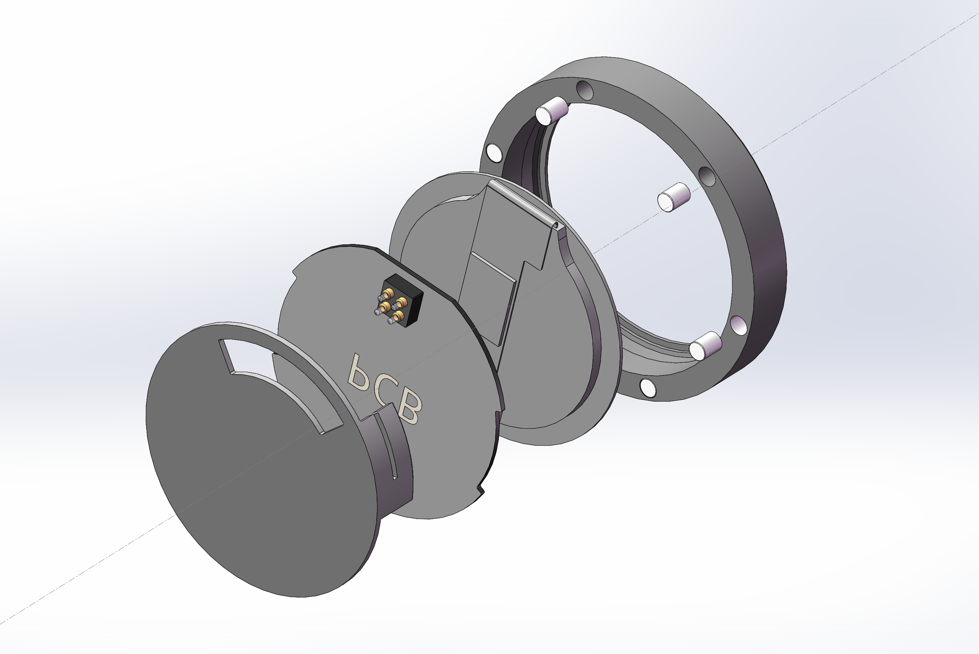
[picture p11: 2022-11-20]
Structure/img/lcd_boom_2.png

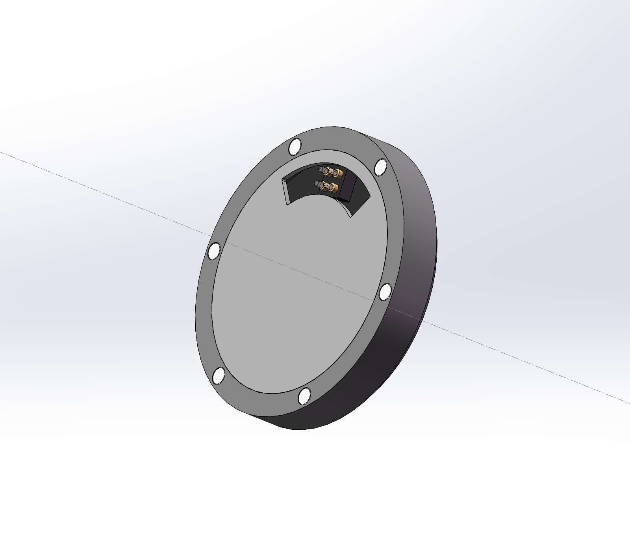
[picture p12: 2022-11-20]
Structure/img/lcd_2.png

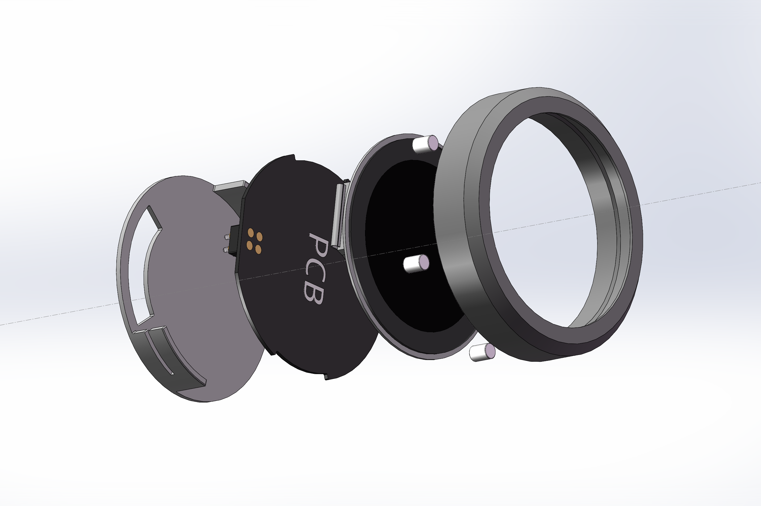
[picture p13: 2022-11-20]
Structure/img/lcd_boom_4.png

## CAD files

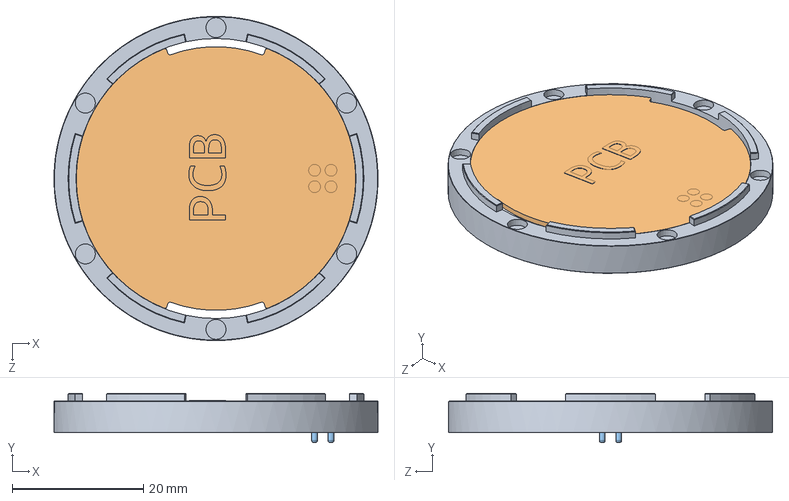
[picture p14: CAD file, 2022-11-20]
Structure/单层模块.SLDASM
49.3 x 7.46 x 49.3 mm
单层模块外壳
单层模块PCB
4Pin弹簧针公座

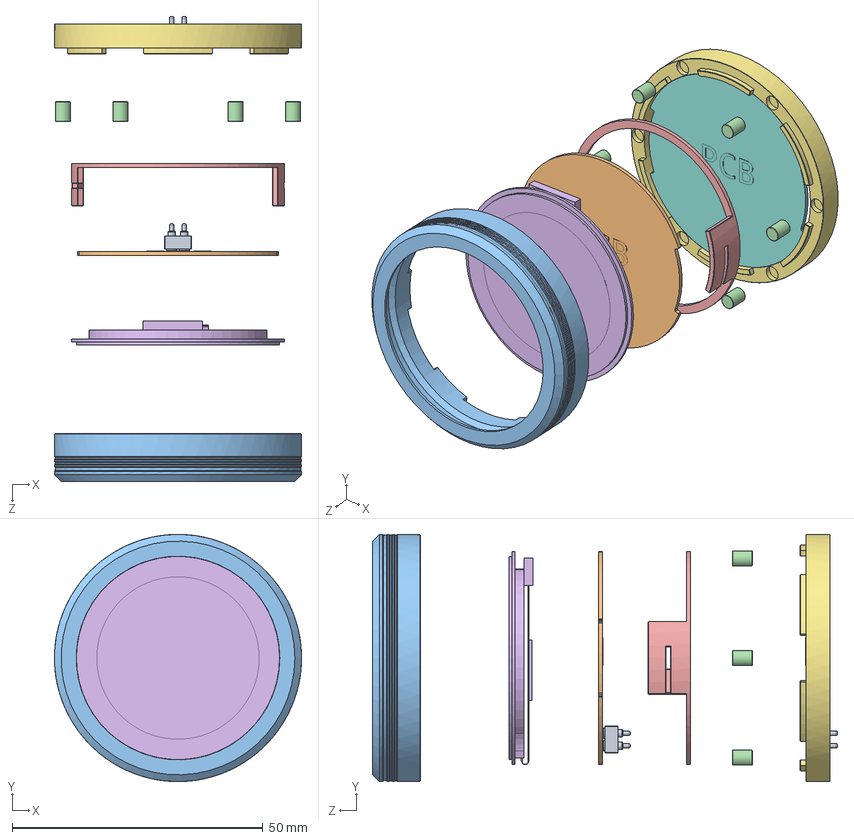
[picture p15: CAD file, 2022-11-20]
Structure/测试装配.SLDASM
49.3 x 49.3 x 92.7 mm
4Pin弹簧针公座 x 2
屏幕模块PCB
屏幕模块外壳
直径3厚度4磁铁 x 6
屏幕模块底盖
1.28寸LCD
单层模块外壳
单层模块PCB

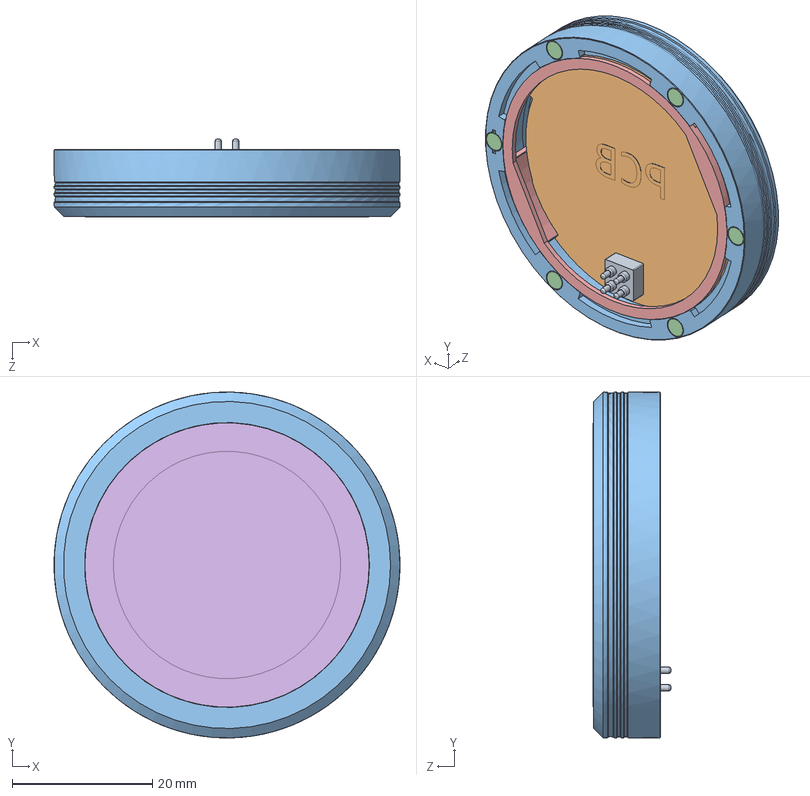
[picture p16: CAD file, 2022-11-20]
Structure/屏幕模块.SLDASM
49.3 x 49.3 x 11.1 mm
4Pin弹簧针公座
屏幕模块PCB
屏幕模块外壳
直径3厚度4磁铁 x 6
屏幕模块底盖
1.28寸LCD

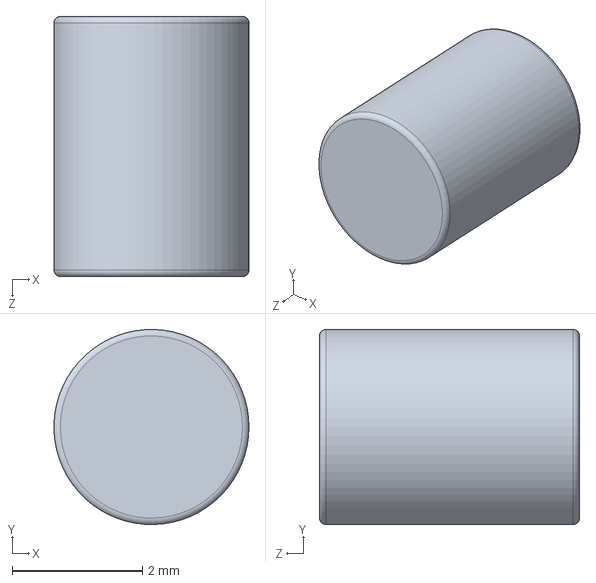
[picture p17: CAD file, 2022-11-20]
Structure/直径3厚度4磁铁.SLDPRT
3.00 x 3.00 x 4.00 mm

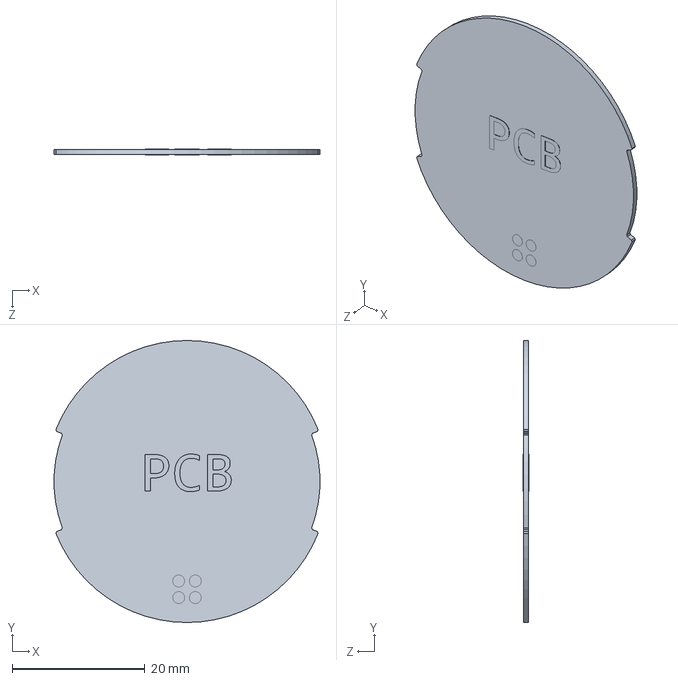
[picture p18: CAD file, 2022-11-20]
Structure/单层模块PCB.SLDPRT
40.0 x 42.5 x 0.9 mm

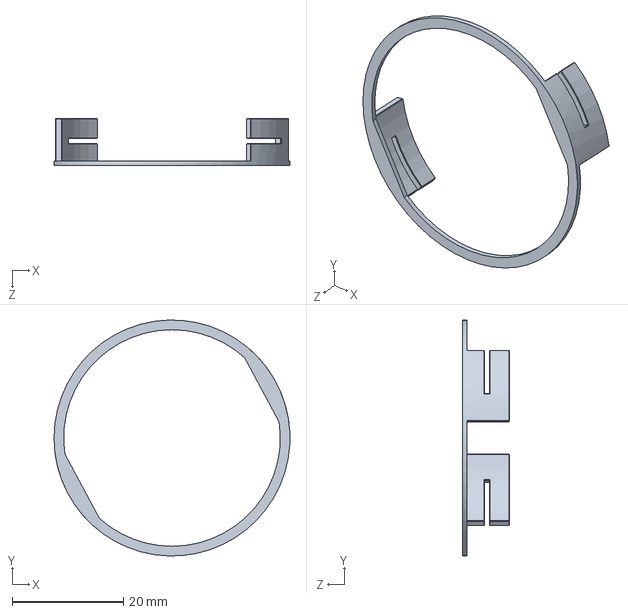
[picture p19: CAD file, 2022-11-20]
Structure/屏幕模块底盖.SLDPRT
42.5 x 42.5 x 8.44 mm

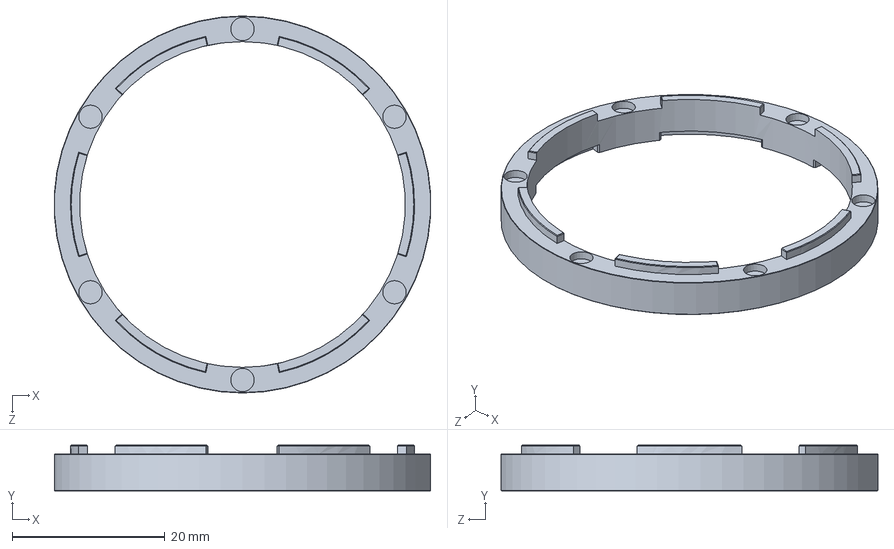
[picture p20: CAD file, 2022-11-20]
Structure/单层模块外壳.SLDPRT
49.2 x 5.97 x 49.3 mm

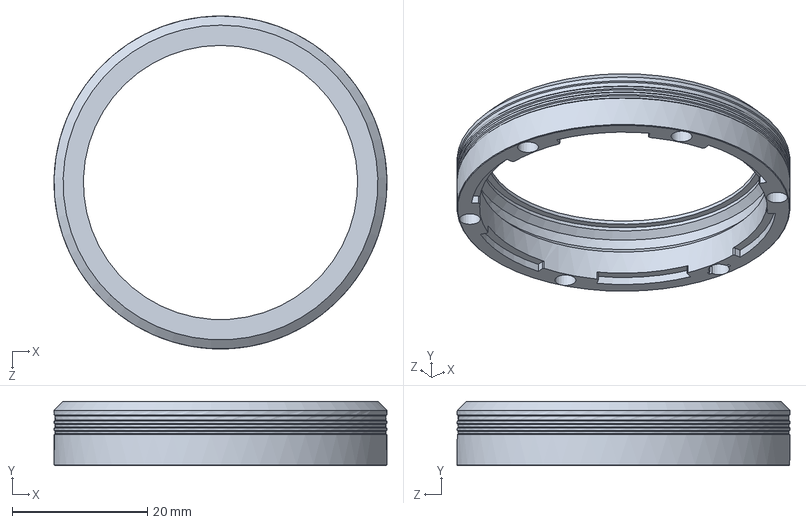
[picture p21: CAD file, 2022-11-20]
Structure/屏幕模块外壳.SLDPRT
49.3 x 9.55 x 49.3 mm

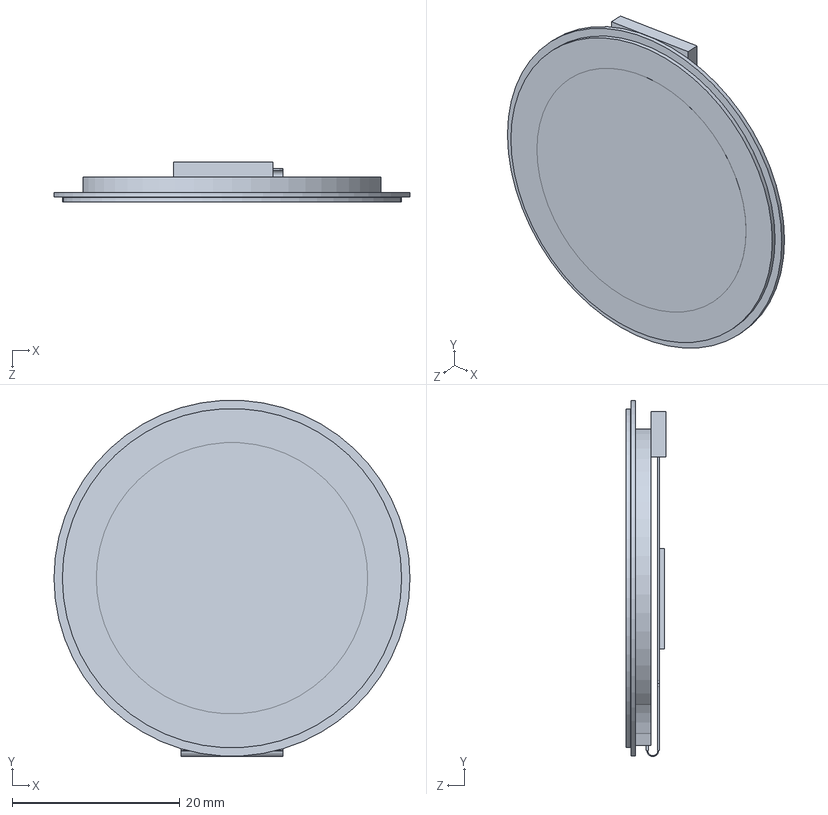
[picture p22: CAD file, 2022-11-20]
Structure/1.28寸LCD.SLDPRT
42.5 x 42.5 x 4.80 mm

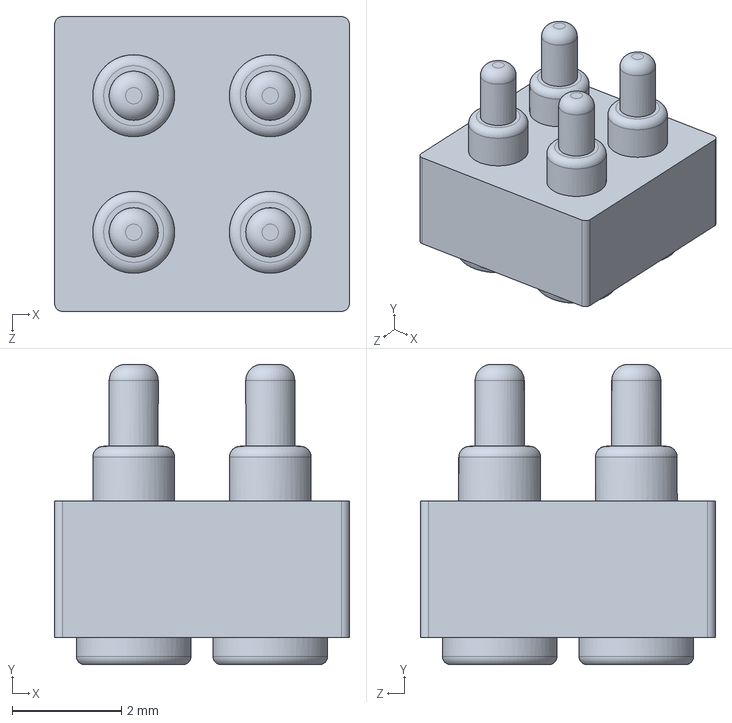
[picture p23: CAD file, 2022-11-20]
Structure/4Pin弹簧针公座.SLDPRT
5.40 x 5.50 x 5.40 mm

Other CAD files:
Structure/屏幕模块PCB.SLDPRT

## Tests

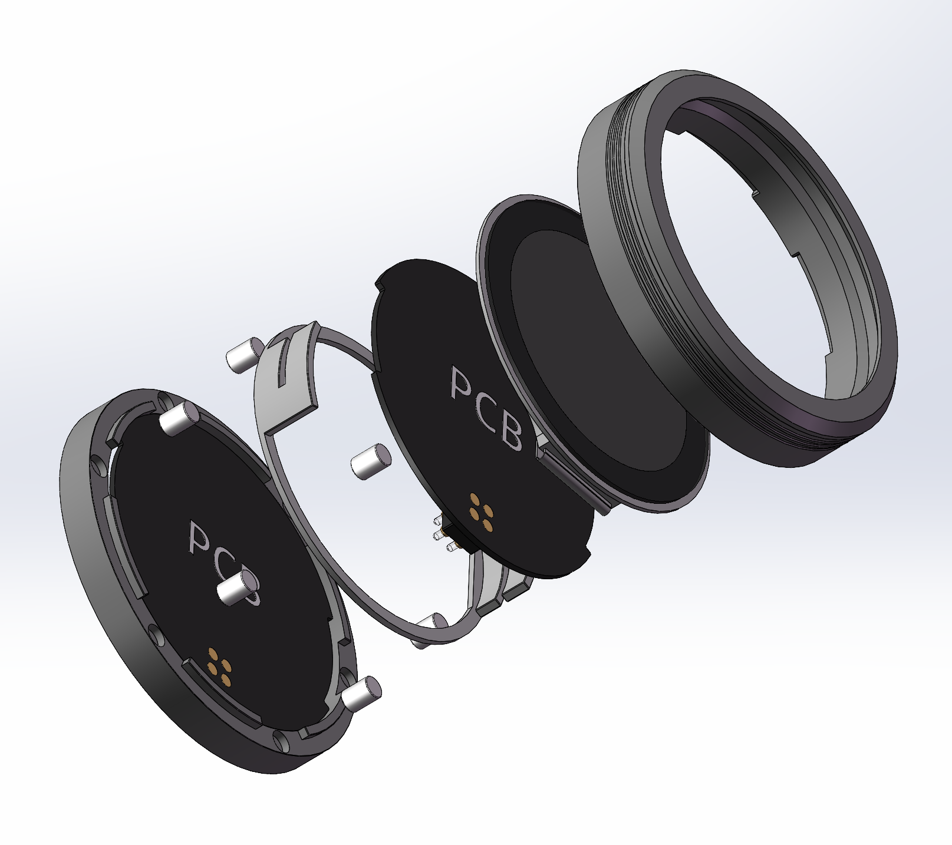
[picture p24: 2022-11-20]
Structure/img/test_boom_1.png

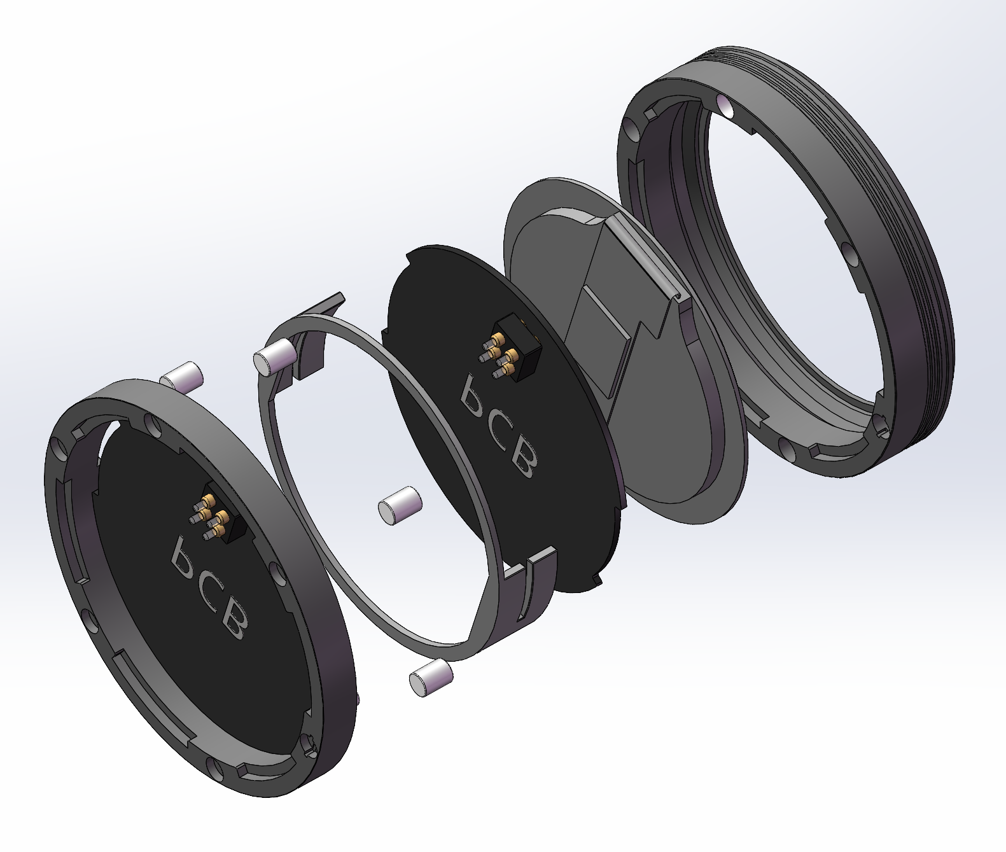
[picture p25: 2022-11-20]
Structure/img/test_boom_2.png

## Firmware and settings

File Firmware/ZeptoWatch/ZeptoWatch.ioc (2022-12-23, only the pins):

Mcu.UserName=STM32F405RGTx
PA0-WKUP.GPIO_Label=KEY_INT
PA0-WKUP.Signal=GPXTI0
PA1.GPIO_Label=BT_RST
PA1.Signal=GPIO_Output
PA11.Signal=USB_OTG_FS_DM
PA12.Signal=USB_OTG_FS_DP
PA13.Signal=SYS_JTMS-SWDIO
PA14.Signal=SYS_JTCK-SWCLK
PA2.Signal=USART2_TX
PA3.Signal=USART2_RX
PA4.Signal=I2S3_WS
PA5.GPIO_Label=LCD_SCL
PA5.Signal=SPI1_SCK
PA6.GPIO_Label=LCD_BLK
PA6.Signal=S_TIM3_CH1
PA7.GPIO_Label=LCD_SDA
PA7.Signal=SPI1_MOSI
PB6.GPIO_Label=MOTOR
PB6.Signal=S_TIM4_CH1
PC0.GPIO_Label=BAT_ADC
PC0.Signal=ADCx_IN10
PC10.Signal=I2S3_CK
PC12.Signal=I2S3_SD
PC14-OSC32_IN.Signal=RCC_OSC32_IN
PC15-OSC32_OUT.Signal=RCC_OSC32_OUT
PC6.Signal=USART6_TX
PC7.Signal=USART6_RX
PH0-OSC_IN.Signal=RCC_OSC_IN
PH1-OSC_OUT.Signal=RCC_OSC_OUT

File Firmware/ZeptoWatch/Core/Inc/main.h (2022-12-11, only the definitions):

#define BAT_ADC_Pin GPIO_PIN_0
#define BAT_ADC_GPIO_Port GPIOC
#define KEY_INT_Pin GPIO_PIN_0
#define KEY_INT_GPIO_Port GPIOA
#define KEY_INT_EXTI_IRQn EXTI0_IRQn
#define BT_RST_Pin GPIO_PIN_1
#define BT_RST_GPIO_Port GPIOA
#define LCD_SCL_Pin GPIO_PIN_5
#define LCD_SCL_GPIO_Port GPIOA
#define LCD_BLK_Pin GPIO_PIN_6
#define LCD_BLK_GPIO_Port GPIOA
#define LCD_SDA_Pin GPIO_PIN_7
#define LCD_SDA_GPIO_Port GPIOA
#define MOTOR_Pin GPIO_PIN_6
#define MOTOR_GPIO_Port GPIOB

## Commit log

2022-10-14 fix(disp): fix port definition(lcd_rst) of gc9a01.
    [gc9a01.h]
2022-10-15 feat(ui, rtc, interrupt): add real-time clock and rotating arrows on the temporary gui.
2022-10-18 refactor(drivers, lcd): move the drivers into separate folders; change the display direction.
2022-10-26 add(lcd_brightness): add lcd brightness adjustor (PWM).
2022-10-28 Revert "perf(disp): distribute display buffer to CCMRAM."
    This reverts commit c00f1c1c137a21c755abb3a43dd8bcffd1adf61c. It induced a display fault for the reason that CCMRAM could not be accessed by peripherals (SPI, DMA).
2022-10-28 refactor(app): rename main folder; create empty framework for application support.
2022-11-20 feat(pcb, sld): add hardware projects; organize folders.
    [1.28寸LCD.SLDPRT, 4Pin弹簧针公座.SLDPRT, 单层模块.SLDASM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]
2022-11-20 style(folders): some unimportant work.
    [1.28寸LCD.SLDPRT, 4Pin弹簧针公座.SLDPRT, 单层模块.SLDASM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]
2022-11-20 doc(readme, imgs): update README.md and sample images.
2022-11-26 feat(hardware): update schematics and pcbs to version 3.0 (not verified yet).
2022-11-27 style(pcb): add some silk screen legends.
2022-11-27 fix(hardware): fix bluetooth wire connection (remove p-mos).
2022-12-02 feat(pikaScript): add module STM32F4.
2022-12-02 fix(lcd, tp): adjust the display direction.
    [cst816.c, cst816.h, gc9a01.c]
2022-12-02 refactor(clock, brightness, delay, etc): polish up user drivers.
2022-12-02 feat(bat_adc): add battery adc; parameters are remained to be determined.
2022-12-02 update(readme, pcb, imgs): update information in schematics; fix a small problem in pcb; update README.md and imgs.
2022-12-08 refactor(usb): Update CubeMX and fix USB MSC; and many other work.
    [ZeptoWatch.ioc, battery.cpp, brightness.cpp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]
2022-12-09 fix(fatfs): successfully read files.
    [cst816.c, cst816.h, gc9a01.h]
2022-12-10 fix(python): scan and run python script.
    [ZeptoWatch.ioc]
2022-12-10 fix(hardware): add a pulling-down resistor on the WKUP pin; update the information on schematics.
2022-12-11 update(schematics): update information on schematics.
2022-12-11 feat(powerkey): add driver code for the power button, like resting and recovering, shuting down and powering up.
2022-12-11 refactor(power): refactor power state manager.
2022-12-11 feat(disp): recover when replace the screen.
    [cst816.c]
2022-12-11 feat(imu): add a nice dynamic chart demo for imu data.
2022-12-11 add(battery): add stop sampling function.
2022-12-11 feat(microphone): add the drivers and a running chart demo for the microphone.
2022-12-12 add(vibrator): add drivers for the vibrator.
    [ZeptoWatch.ioc, vibrator.cpp]
2022-12-12 feat(interfaces): add some interfaces for the new devices for PikaScript.
2022-12-13 feat(ui, home, dropdown): add ui framework; add dropdown menu.
2022-12-15 feat(program): add program running support. (with some restrictions due to bugs which are remained unrepaired)
    [ZeptoWatch.ioc, rtc.c]
2022-12-15 fix(clock): fix the problem that time label is not updated in the applications.
    [rtc.c]
2022-12-16 fix(powerkey): fix the problem of automatically waking up from standby mode.
    [power.cpp]
2022-12-17 fix(heap, stack): modifications seem to induce no problem.
    [ZeptoWatch.ioc]
2022-12-17 update(schematics): update comments.
2022-12-19 update(schematics): update the comments.
2022-12-22 feat(settings, electronic woodfish); fix(many things).
    [ZeptoWatch.ioc, battery.cpp, brightness.cpp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]
2022-12-23 fix(mutex): [important] consider lvgl thread safety issues, fix most of the crash cases, and greatly improve stability.
    [ZeptoWatch.ioc]
2022-12-23 feat(imu demos): add gravity and wall simulators.

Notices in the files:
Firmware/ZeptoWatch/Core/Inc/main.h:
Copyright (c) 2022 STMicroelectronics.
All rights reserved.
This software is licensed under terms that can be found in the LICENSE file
